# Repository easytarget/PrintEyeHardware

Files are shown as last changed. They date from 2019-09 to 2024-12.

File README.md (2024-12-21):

# Depreciated!

RRF 3.5.0 and later no longer support the M408 information fetch command used by PrintEYE

See : https://github.com/easytarget/PrintPy2040
- This is a replacement based on the new ObjectModel data system
- It uses a RP2040 MCU, is smaller, does not need a custom PCB and looks better!

For Posterity: (I am archiving this repo now)

# Duet 'PrintEye' temperature display hardware
## This repository is dedicated to the Hardware used in the printEye; For the full firmware and project description please go to:
## https://github.com/easytarget/PrintEye

This is a low cost and lightweight temperature and status monitor for 3d Printers using Duet (or other repRap Firmware) controllers.

* Atmega328P based
* 2 x 0.96' OLED displays on individual I2C busses
* Level Shifter for Serial connections (duet is 3.3v, 328p is 5v)
* A button
* A LED
* A case
* I include the full KiCad project, exported Gerber Files and more.

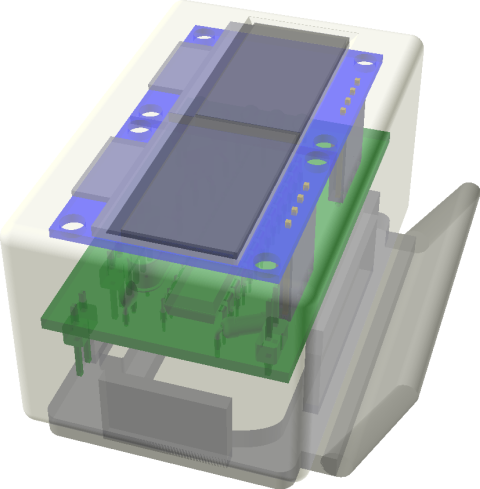
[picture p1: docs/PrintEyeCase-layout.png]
Case Fitting


PCB Notes:
* The layout is single sided (despite the render above).
  * There are three bridges that need to be placed on the top side.
* Track and pad size+spacing in the PCB layout is pretty generous, but this is a smallish board so some care is needed ;-)
* The FTDI connector needs to be placed on the reverse (copper) side of the PCB.

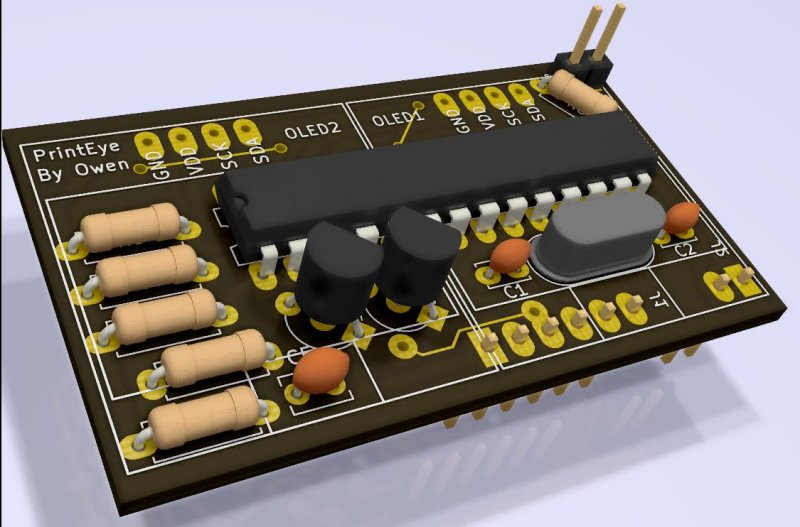
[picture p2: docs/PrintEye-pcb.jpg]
PCB


The included case is designed to have the OLED panels glued in place. The PCB then mounts onto their connectors.
* Glue it lightly! I used generic contact adhesive; this is strong enough but will allow the displays to be gently levered out if needed in the future.
* The case back is a press fit, the plug slot in the back is sized for a dupont connector.
* Fitting and mounting the LED and button I leave up to you.
  * I used thin insulated solid core wires to hold the LED positioned between the two OLED connectors, with a translucent case this is very effective, the LED shines through the lower front of the case itself.
  * The button recess is sized for a 12mm diameter button; glue it in place and then run wires to the PCB. I used a dupont connector here too.

#### Schematic ([Full](./docs/PrintEye-Schematic.pdf))
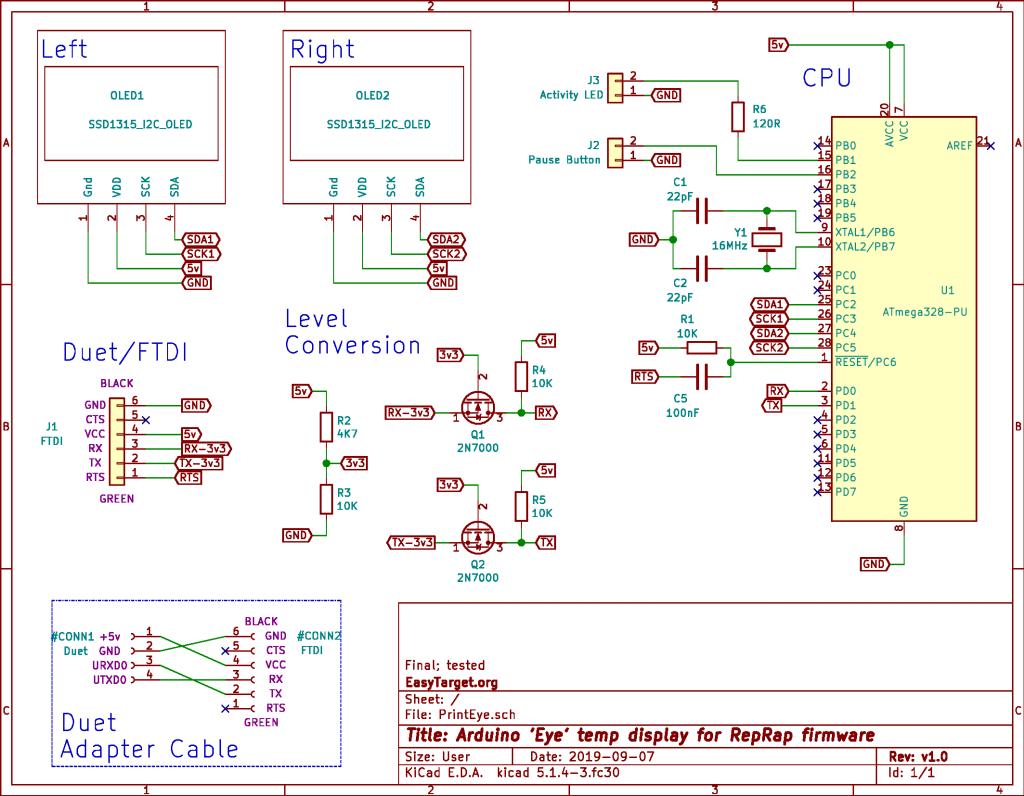
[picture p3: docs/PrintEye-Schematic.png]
Schematic


#### Parts List:

|Ref|Qnty|Value|KiCad Part|Description|
|---|----|-----|----|---|
|C1,C2|2|22pF|Device:C|Unpolarized capacitor|
|C5|1|100nF|Device:C|Unpolarized capacitor|
|OLED1,OLED2|2|SSD1315_I2C_OLED|OLED|0.96' OLED I2C display|
|Q1,Q2|2|2N7000|Transistor_FET:2N7000|N-Channel MOSFET, 2.6V Logic Level, TO-92|
|R1,R3,R4,R5|4|10K|Device:R|Resistor|
|R2|1|4K7|Device:R|Resistor|
|R6|1|120R|Device:R|Resistor|
|U1|1|ATmega328-PU|MCU_Microchip_ATmega:ATmega328-PU|20MHz, 32kB Flash, 2kB SRAM, 1kB EEPROM, DIP-28|
|Y1|1|16MHz|Device:Crystal|HC49-4H_Vertical	Two pin crystal|

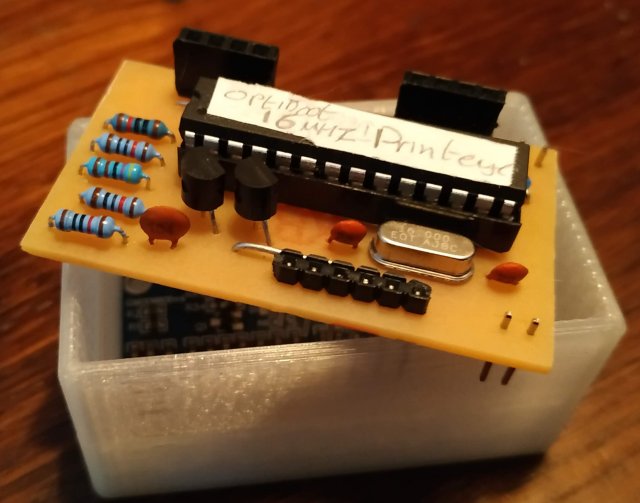
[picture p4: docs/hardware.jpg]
Hardware


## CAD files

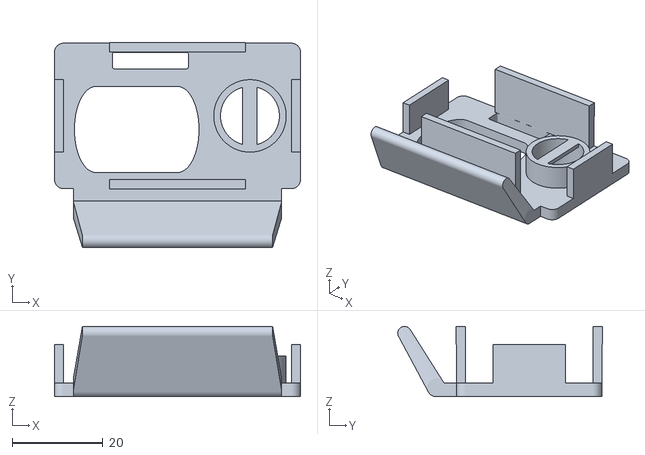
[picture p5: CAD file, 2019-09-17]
PrintEyeCaseStand.stl
54.3 x 45.1 x 15.5

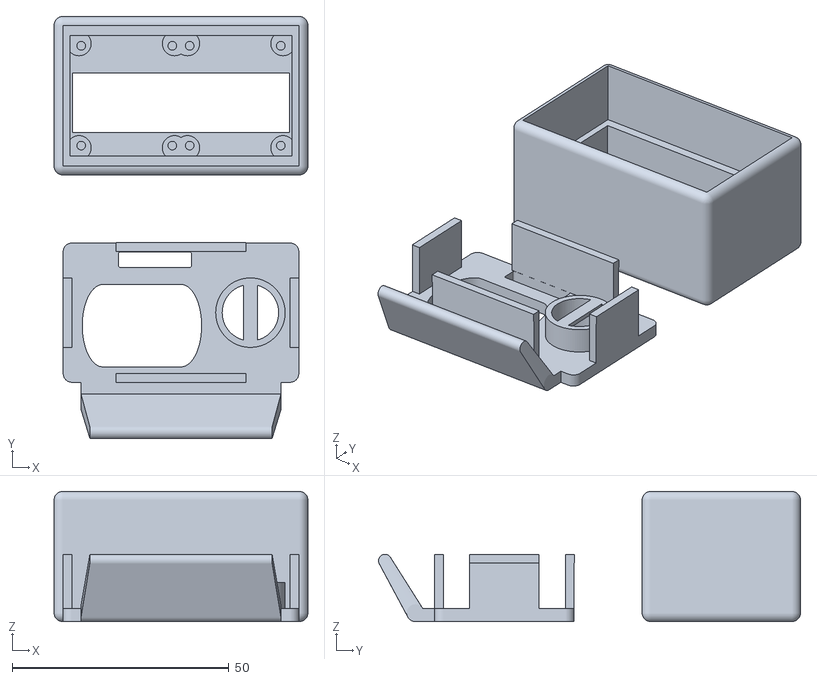
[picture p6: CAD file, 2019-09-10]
PrintEyeCase.stl
58.5 x 97.2 x 30.0

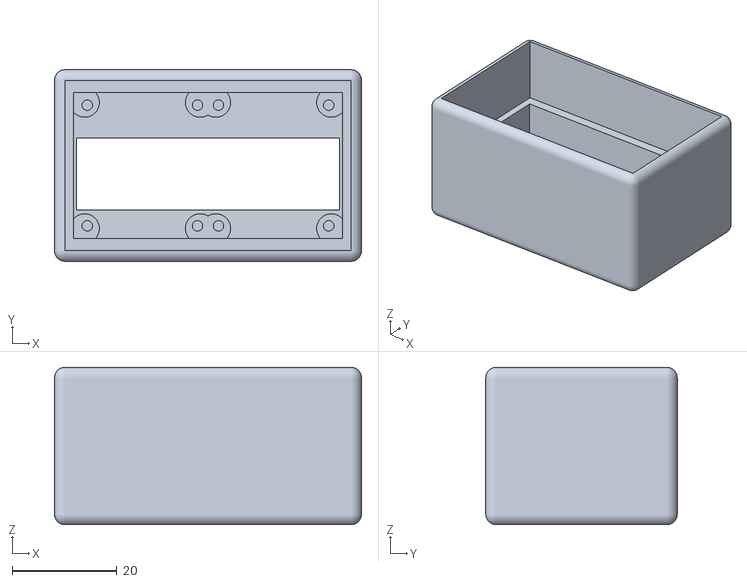
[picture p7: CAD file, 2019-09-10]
PrintEyeCaseBody.stl
58.5 x 36.5 x 30.0

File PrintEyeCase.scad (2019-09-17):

// Printeye Case
$fn=90; // or fugly

pcbx=53.5; // taken from the pcb as made
pcby=31.5; // not from the model

edgeRad=2;  // round off

fitting = true;

if(!fitting) {
    casebody();
    translate([0,-50,33]) rotate([0,180,0])
    casestand();
} else {
    translate([-pcbx/2,pcby/2,17])
    rotate([180,0,0])
    pcb();
    color("grey",0.4) casestand();
    color("lavender",0.4) casebody();
}

module casestand() {
    // Four tabs to grip onto case, wider at top
    translate([0,0,17.5])
    linear_extrude(height=4,convexity=8) {
        difference() {
            union() {
                //square([pcbx+1,16],center=true);
                square([30,pcby+0.8],center=true);
            }
            square([pcbx-3.2,pcby-3.4],center=true);
        }
    }
    // Thinner part of tabs
    translate([0,0,21.5])
    linear_extrude(height=10,convexity=8) {
        difference() {
            union() {
                square([pcbx+0.8,16],center=true);
                square([30,pcby+0.6],center=true);
            }
            square([pcbx-3.2,pcby-3.4],center=true);
        }
    }
    //Plate over the whole thing with cutouts.
    // color("grey",0.5) // handy 4 debug
    translate([0,0,30])
    linear_extrude(height=3,convexity=8) {
        difference() {
            minkowski() {
                square([pcbx-3.2,pcby-3.4],center=true);
                circle(2);
            }
            translate([-16,0]) circle(d=13); // button
            
            hull() { // air/inspect/prodding hole
                translate([0,-3])
                scale([0.5,1]) circle(d=19); 
                translate([18,-3])
                scale([0.5,1]) circle(d=19); 
            }
            minkowski() { // cable slot)
                translate([-2,10.8])
                square([16,2.8]);
                circle(0.4);
            }
        }
        translate([0,-18])
        square([46,5],center=true);
    }
    // foot
    translate([0,-20.5,31]) 
    hull() {
        rotate([0,90,0])
        cylinder(d=4,h=46,center=true);
        translate([0,-7,-12])
        rotate([0,90,0])
        cylinder(d=3,h=42,center=true);
    }
    
    // Button recess
    translate([-16,0,24])
    linear_extrude(height=9,convexity=8) {
        difference() {
            circle(d=16);
            circle(d=13);
        }
    }
    translate([-16,0,24])
    linear_extrude(height=1,convexity=8) {
        intersection() {
            circle(d=16);
            square([3.2,18],center=true);
        }
    }
}

module casebody() {
    difference() {
        minkowski() {
            translate([0,0,15])
            cube([pcbx+1,pcby+1,30-2*edgeRad],center=true);
            sphere(edgeRad);
        }
        // lenses
        hull() {
            translate([0,-1.6,0])
            cube([52,15.6,0.1],center=true);
            translate([0,-1.6,1])
            cube([50,13.6,0.1],center=true);
        }
        // pcbs
        // Section with fat pins to support oleds
        translate([0,0,1])
        linear_extrude(height=2,convexity=8) {
            difference() {
                square([51.2,27.8],center=true);
                for(x=[-23.5,-1.5,1.5,23.5],
                    y=[-12,12])
                translate([x,y]) circle(2.8);
            }
        }
        // Now the bit with the pin tops
        translate([0,0,2.8])
        linear_extrude(height=30,convexity=8) {
            difference() {
                square([51.2,27.8],center=true);
                for(x=[-23,-2,2,23],
                    y=[-11.5,11.5])
                translate([x,y]) circle(1);
            }
        }
        // Now the rest
        translate([0,0,4])
        linear_extrude(height=30,convexity=8) {
            square([51.2,27.8],center=true);
        }
        
        translate([0,0,15.5])
        linear_extrude(height=60,convexity=8) {
            square([pcbx+1,pcby+0.8],center=true);
        }
    }
}

module pcb(opacity=0.5) {
    color("green",opacity)
    import("PrintEyePcb.stl");
    translate([13.6,15.3,13.3])
    rotate([0,0,90]) 
    oled(alpha=opacity);
    translate([38.5,15.3,13.3])
    rotate([0,0,90]) 
    oled(alpha=opacity);
}

module oled(alpha=0.5) {
    color("blue",alpha)
    linear_extrude(height=1.2,convexity=5) 
    difference() {
        square([27,25],center=true);
        for(x=[-11.5,11.5],y=[-10.5,10.5])
           translate([x,y]) circle(1.5);
    }
    color("grey",alpha) {
        translate([0,0,1.3])
        linear_extrude(height=1.4,convexity=5)
        square([16.6,24.8],center=true);
        translate([-10,0,1.3])
        linear_extrude(height=0.8,convexity=5)
        square([7,12],center=true);
        translate([2,0,1.3])
        linear_extrude(height=1.8,convexity=5)
        square([13.5,24.8],center=true);
    }
    
    for(y=[-3.81,-1.27,1.27,3.81]) {
        color("gold",alpha)
        translate([12,y,-11.7])
        linear_extrude(height=13.7,convexity=5)
        square([0.6,0.6],center=true);
        color("grey",0.8)
        translate([12,y,-11.7])
        linear_extrude(height=11.7,convexity=5)
        square([2,2.6],center=true);
    }
} 

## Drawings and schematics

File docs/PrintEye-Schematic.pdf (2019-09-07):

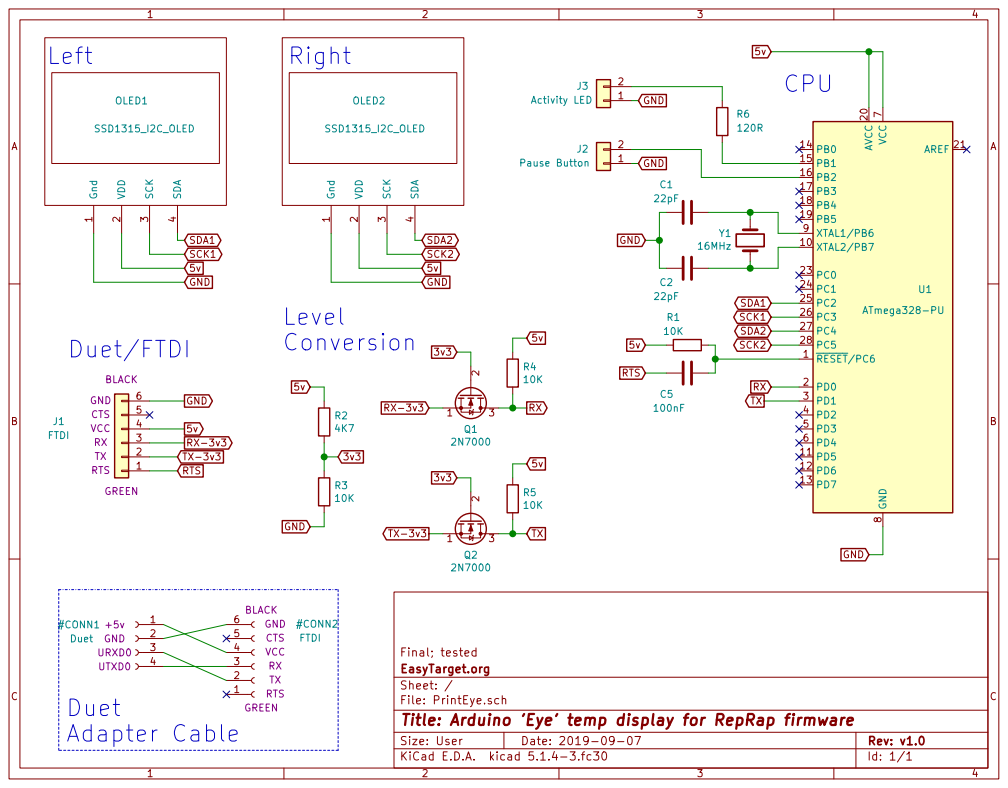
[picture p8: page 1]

Final; tested
File: PrintEye.sch Sheet: / EasyTarget.org

Id: 1/1 Title: Arduino 'Eye' temp display for RepRap firmware

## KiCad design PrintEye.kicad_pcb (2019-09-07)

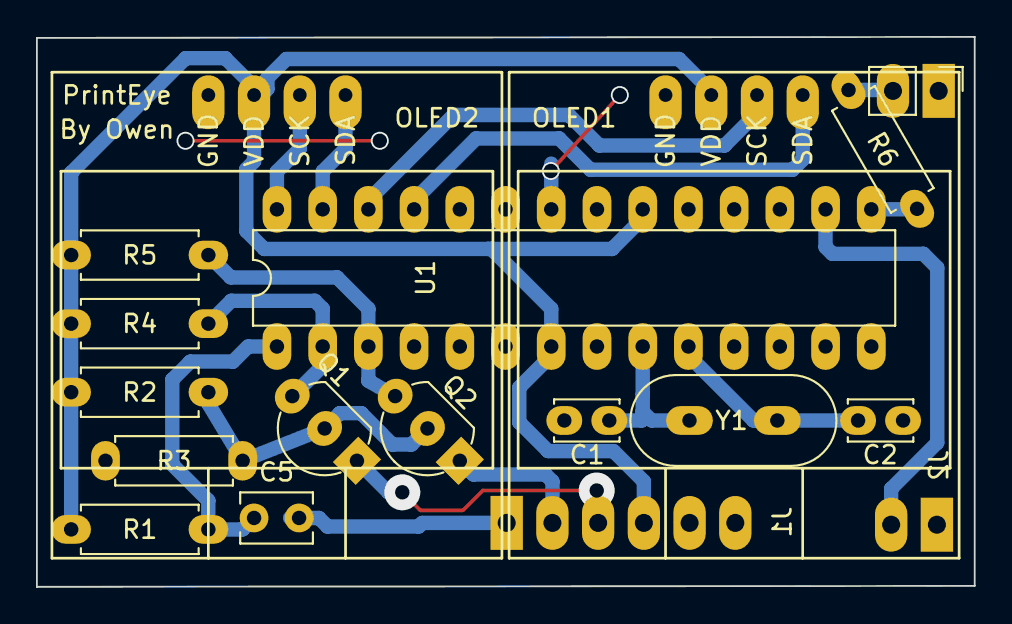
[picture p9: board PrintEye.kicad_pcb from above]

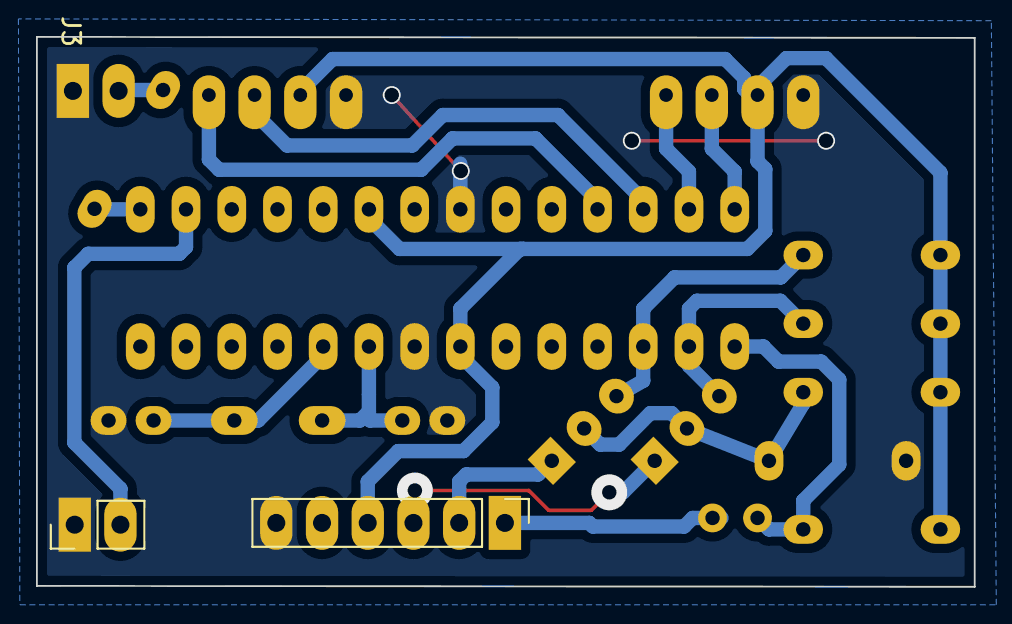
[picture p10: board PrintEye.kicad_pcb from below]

Board: 2 copper layers, 52.1 x 30.6 mm, 18 parts (2 on the bottom side), 18 nets.

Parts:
C1, C2: 22pF; C_Disc_D3.4mm_W2.1mm_P2.50mm
C5: 100nF; C_Disc_D3.8mm_W2.6mm_P2.50mm
J1: FTDI; PinHeader_1x06_P2.54mm_Vertical
J2: Pause Button; PinHeader_1x02_P2.54mm_Vertical
J3: Activity LED; PinHeader_1x02_P2.54mm_Vertical
OLED1, OLED2: SSD1315_I2C_OLED; SSD1315-I2C-OLED
Q1, Q2: 2N7000; TO-92_Inline_Wide
R1, R3, R4, R5: 10K; R_Axial_DIN0207_L6.3mm_D2.5mm_P7.62mm_Horizontal
R2: 4K7; R_Axial_DIN0207_L6.3mm_D2.5mm_P7.62mm_Horizontal
R6: 120R; R_Axial_DIN0207_L6.3mm_D2.5mm_P7.62mm_Horizontal
U1: ATmega328-PU; DIP-28_W7.62mm
Y1: 16MHz; Crystal_HC49-4H_Vertical

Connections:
3v3: Q1.2, Q2.2, R2.2, R3.1
5v: J1.4, OLED1.2, OLED2.2, R1.2, R2.1, R4.1, R5.1, U1.7, U1.20
GND: C1.1, C2.1, J1.6, J2.1, J3.1, OLED1.1, OLED2.1, R3.2, U1.8, U1.22
unnamed: C1.2, U1.9, Y1.2
unnamed: C2.2, U1.10, Y1.1
unnamed: C5.1, R1.1, U1.1
unnamed: J2.2, U1.16
unnamed: J3.2, R6.2
unnamed: R6.1, U1.15
RTS: C5.2, J1.1
RX: Q1.3, R4.2, U1.2
RX-3v3: J1.3, Q1.1
SCK1: OLED1.3, U1.26
SCK2: OLED2.3, U1.28
SDA1: OLED1.4, U1.25
SDA2: OLED2.4, U1.27
TX: Q2.3, R5.2, U1.3
TX-3v3: J1.2, Q2.1

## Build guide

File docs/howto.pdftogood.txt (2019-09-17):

# Make sure you have ImageMagick installed; then run:
convert -alpha off -density 300 Schematic.pdf Schematic.jpg

# Should give a reasonable result; playing with density can improve/decrease legibility.
# Dont turn alpha on unless you like having the page background displayed through the image..

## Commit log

2019-06-28 Schematic PDF
2019-09-03 Bring up-to-date from my laptop
    [EyeDrop.kicad_pcb, EyeDrop.sch, PrintEye.kicad_pcb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]
2019-09-03 Symbol Lib for the OLED
    [PrintEye.sch]
2019-09-03 PCB design and footprints
    [PrintEye.kicad_pcb, PrintEye.sch]
2019-09-03 Swap TX and RX..
    [PrintEye.kicad_pcb, PrintEye.sch]
2019-09-03 Move to a bigger connector size
    [PrintEye.kicad_pcb, PrintEye.sch]
2019-09-04 Documentation; update metadata in Schematic
    [PrintEye.kicad_pcb, PrintEye.sch]
2019-09-04 Track widths and clearances
    [PrintEye.kicad_pcb]
2019-09-04 Capacitor ended up joined on PCB, trivial correction to it's pads
    [PrintEye.kicad_pcb]
2019-09-07 Update with final schematic and pcb revs
    [PrintEye.kicad_pcb, PrintEye.sch, PrintEyeCase.scad]
2019-09-07 Case Mk1, no base as yet, no button mount either.
    [PrintEyeCase.scad, PrintEyeCase.stl]
2019-09-10 Final Case bits, gerber files.
    [PrintEyeCase.scad, PrintEyeCase.stl, PrintEyeCaseBody.stl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]
2019-09-17 Update README with a BOM etc.
2019-09-17 Updated images
    [PrintEyeCase.scad, PrintEyeCaseStand.stl]
2019-09-18 Switch to github
